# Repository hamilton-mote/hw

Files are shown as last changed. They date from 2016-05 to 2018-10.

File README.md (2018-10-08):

# Hamilton open-source hardware

hamilton mote

The Hamilton mote (so named for its $10 cost) is a mote based on the ATSAMR21E18A (similar to the MCU present on the Atmel SAMR21XPRO). The low-cost variboard has an accelerometer, a temperature sensor and a light sensor as well as four GPIO pins and an I2C bus. To disseminate sensor data, it uses the 802.15.4 wireless radio built into the SAMR21. The board is not designed to offer huge amounts of GPIO (the [storm](http://storm.rocks) is designed for that), but rather be a platform for low cost wireless sensors that can be deployed en-masse without massive financial outlay.

The primary operating system we support is RIOT-OS. Soon we hope to get support upstream into the RIOT codebase, but for now we will maintain a rebasing fork, broken into feature-branches that can be individually merged on top of upstream.

# Sensor packages

A hamilton board will have a sensor variant designator in its name, for example hamilton-3 or hamilton-1f. This variant indicates the presence of a subset of the following sensors

| Designation  | Description | Part number |
|:---:|:---:|:---:|
|  1 | Low-cost temperature sensor | AT30TS74 |
|  2 | Low-cost 3-axis accelerometer | MMA7660 |
|  4 | Light sensor | APDS-9007 |
|  8 | High-precision 3-axis accel/magnetometer | FXOS8700 |
| 10 | Temp / Humidity sensor | HDC1080 |
| 20 | Temp / Radiant sensor | TMP006 |
| 40 | PIR sensor | EKMB110x11x |
| 80 | Ultrasonic ranger | CH201 |
| 100 | High-precision 3-axis accel/magnetometer | LSM303C |
| 200 | Light sensor | ISL29035 |

So far, we have produced three hamilton bundles:

- Hamilton-7 (4+2+1), which costs $10 including the sensors and is designed for cost-sensitive applications
- Hamilton-3C (20+10+8+4), cost TBD, which is designed as an operative temperature sensor with acceleration/magnetometer so it can determine its orientation in the space
- Hamilton-7C (40+20+10+8+4), cost TBD, which adds occupancy (the occupancy sensor doubles the cost of the board)
- Hamilton-330 (200+100+20+10), a replacement for the 3C which has better light sensing and a more readily available accelerometer
- Hamilton-370 (200+100+40+20+10), a replacement for the 7C which adds PIR to the 330

The expected battery life of each of these variants will be put on here when they have been characterised

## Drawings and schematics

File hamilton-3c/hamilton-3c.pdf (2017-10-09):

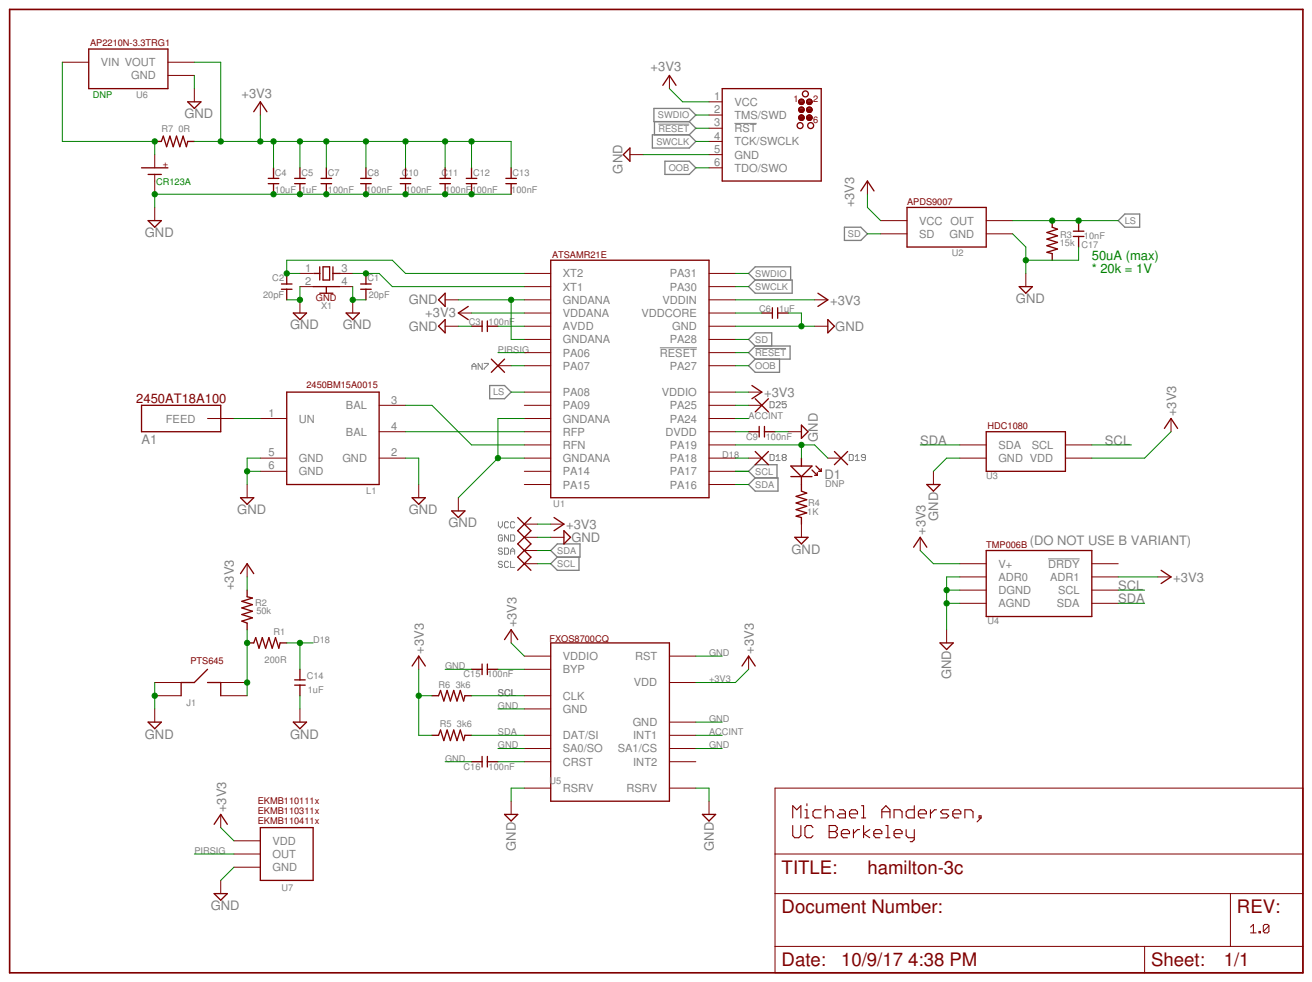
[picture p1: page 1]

XT2 XT1 GNDANA
PA06 PA07 PA08 PA09 GNDANA RFP RFN GNDANA

(DO NOT USE B VARIANT)
SCL ADR1 DRDY

Document Number: | REV:

Date: 10/9/17 4:38 PM | Sheet: 1/1

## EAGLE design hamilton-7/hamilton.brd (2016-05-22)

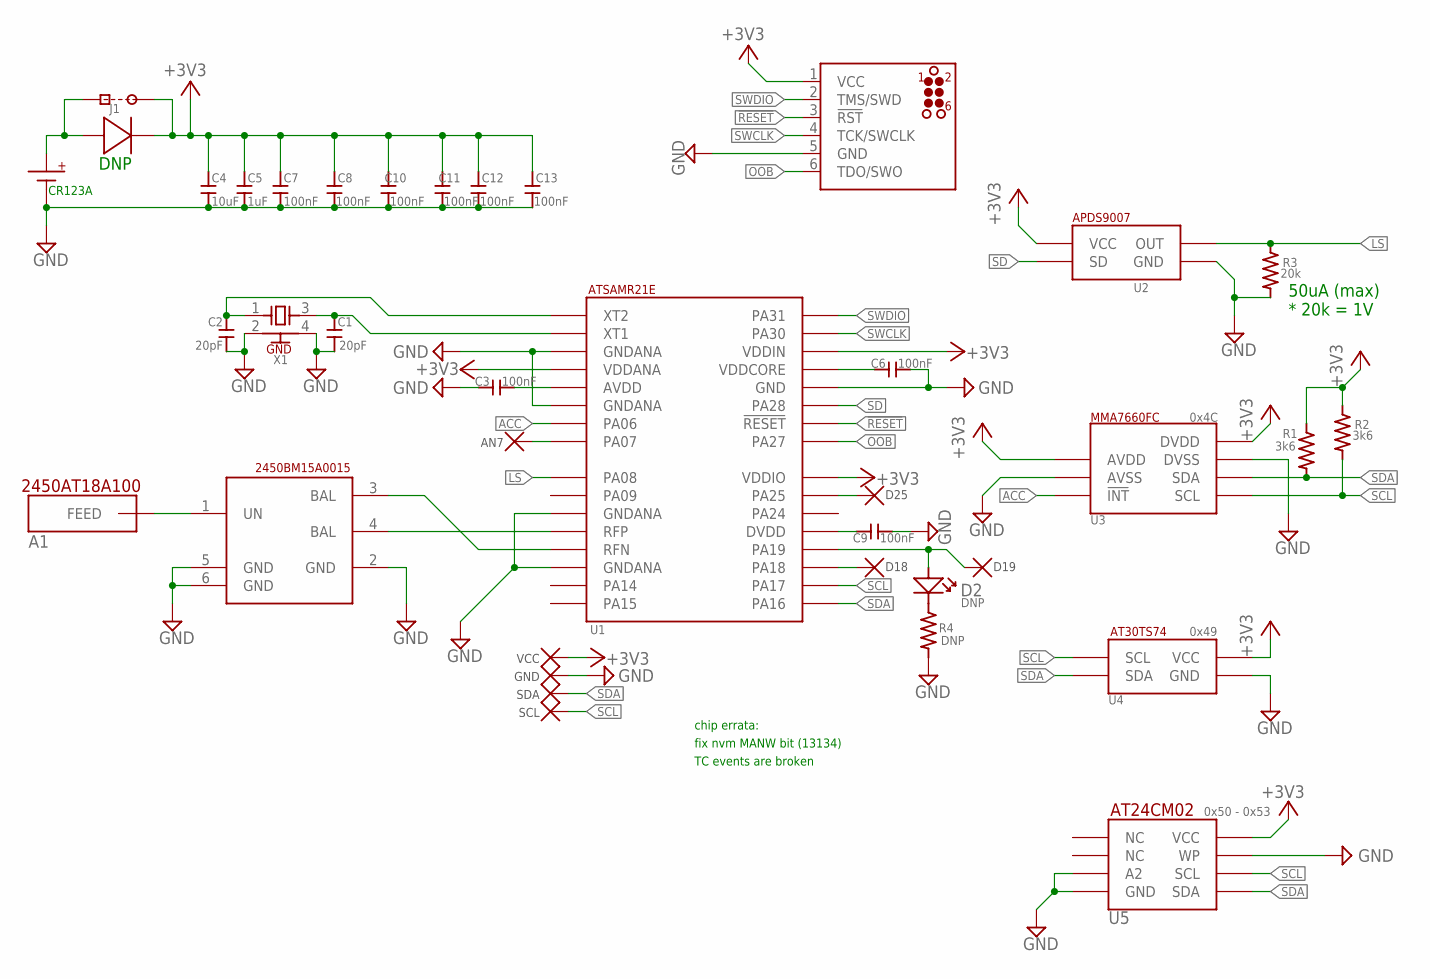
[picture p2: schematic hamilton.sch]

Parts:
A1: JOHANSON_ANTENNA2
BT1: 2/3A
C1, C2: 20pF; S0402
C3, C6, C7, C8, C9, C10, C11, C12, C13: 100nF; C0402
C4: 10uF; 0805
C5: 1uF; C0402
D1: SOD523F
D2: DNP; LINE_0805
J1: CUTJ2; CUT3
L1: BALUN_JOHANSON
R1, R2: 3k6; S0402
R3: 20k; S0402
R4: DNP; S0402
TP1: D19; TPP
TP2: D18; TPP
TP3: AN7; TPP
TP4: D25; TPP
TP5: VCC; TPP
TP6: GND; TPP
TP7: SDA; TPP
TP8: SCL; TPP
U1: SAMR21; QFN32
U2: APDS9007
U3: MMA7660FC; MMA7660
U4: AT30TS74; 4WLCSP
U5: AT24CM02; SO8
U$1: JLINK_CONNECT; TC2030-MCP-NL
X1: XTAL

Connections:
!RESET!: U1.26 (!RESET!), U$1.3 (!RST!)
+3V3: C4.2, C5.2, C7.1, C8.1, C10.1, C11.1, C12.1, C13.1, D1.NEG, J1.P$1 (R), R1.P$2, R2.P$2, TP5.P$1, U1.4 (VDDANA), U1.24 (VDDIO), U1.30 (VDDIN), U2.4 (VCC), U3.3 (AVDD), U3.9 (DVDD), U4.A1 (VCC), U5.8 (VCC), U$1.1 (VCC)
ACC: U1.7 (PA06), U3.5 (!INT!)
GND: BT1.NEG (-), C1.P$1, C2.P$1, C3.2, C4.1, C5.1, C6.1, C7.2, C8.2, C9.1, C10.2, C11.2, C12.2, C13.2, L1.2 (GND), L1.5 (GND), L1.6 (GND), R3.P$1, R4.P$1, TP6.P$1, U1.3 (GNDANA), U1.6 (GNDANA), U1.11 (GNDANA), U1.14 (GNDANA), U1.28 (GND), U2.1 (GND), U3.4 (AVSS), U3.8 (DVSS), U4.A2 (GND), U5.3 (A2), U5.4 (GND), U5.7 (WP), U$1.5 (GND), X1.2 (GND), X1.4 (GND)
LS: R3.P$2, U1.9 (PA08), U2.3 (OUT)
unnamed: BT1.POS (+), D1.POS, J1.P$2 (SQ)
unnamed: L1.3 (BAL), U1.13 (RFN)
unnamed: A1.FEED, L1.1 (UN)
unnamed: C2.P$2, U1.1 (XT2), X1.1 (X1)
unnamed: C6.2, U1.29 (VDDCORE)
unnamed: C3.1, U1.5 (AVDD)
unnamed: C1.P$2, U1.2 (XT1), X1.3 (X2)
unnamed: TP3.P$1, U1.8 (PA07)
unnamed: TP4.P$1, U1.23 (PA25)
unnamed: C9.2, U1.21 (DVDD)
unnamed: D2.NOLINE (+), TP1.P$1, U1.20 (PA19)
unnamed: TP2.P$1, U1.19 (PA18)
unnamed: L1.4 (BAL), U1.12 (RFP)
unnamed: D2.LINE (-), R4.P$2
OOB: U1.25 (PA27), U$1.6 (TDO/SWO)
SCL: R2.P$1, TP8.P$1, U1.18 (PA17), U3.6 (SCL), U4.B2 (SCL), U5.6 (SCL)
SD: U1.27 (PA28), U2.6 (SD)
SDA: R1.P$1, TP7.P$1, U1.17 (PA16), U3.7 (SDA), U4.B1 (SDA), U5.5 (SDA)
SWCLK: U1.31 (PA30), U$1.4 (TCK/SWCLK)
SWDIO: U1.32 (PA31), U$1.2 (TMS/SWD)

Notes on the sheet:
chip errata:
fix nvm MANW bit (13134)
TC events are broken
CR123A
DNP
50uA (max) * 20k = 1V
0x49
0x4C
0x50 - 0x53

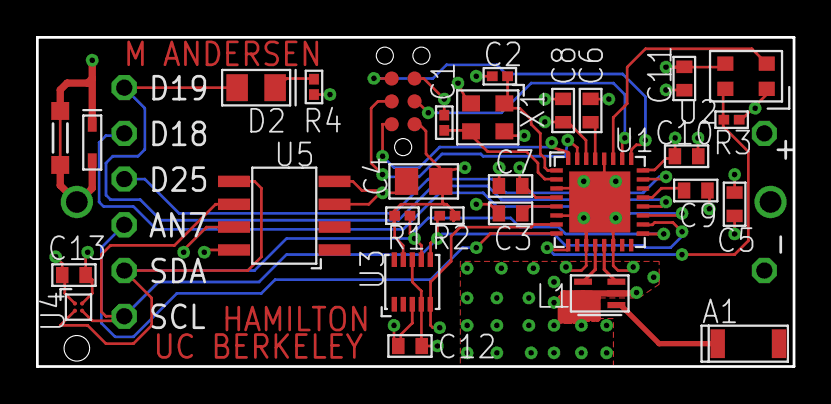
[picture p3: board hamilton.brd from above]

Board: 4 copper layers, 42.0 x 18.3 mm, 38 parts (1 on the bottom side), 25 nets.

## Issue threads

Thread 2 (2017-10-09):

Board files don't match produced boards

ppannuto, 2017-10-09:
I've identified:
 - rightmost sensor as the HDC1080 (a "10")
 - upper right as the APDA-9007 (a "4")
 - left of the SAMR21 as the FXOS8700 (an "8")
 - just below the SAMR21 as the balun
 - top left of the SAMR21 as the crystal
 - and hiding at the top left of the board a AT30TS74 (a "1")

I don't know what I have, but it doesn't match the table for a 3C, so I have a (1+4+8+10)?

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

@Hyungsin this is going to be a problem for everyone trying to figure out what they need to power off if they can't figure out what's on the board -- @nealjack @adkinsjd and I struggled for half an hour to figure out what's going on and I think this is right?

Hyungsin, 2017-10-09:
Hi Pat,

This is what you have.
I will announce it. Thanks.
Also, can you present two papers together on 10/19? Tock and Oppcast.

[image: Inline image 1]

-----------------------------------------------------------------------
*Hyung-Sin Kim*
Postdoctoral Researcher
Electrical Engineering and Computer Science
University of California, Berkeley
Homepage:
https://sites.google.com/site/netlabhome/people/alumni/hyung-sin-kim

On Sun, Oct 8, 2017 at 6:38 PM, Pat Pannuto <notifications@github.com>
wrote:

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

ppannuto, 2017-10-09:
Are the I/O connections correct?

What are the addresses of each sensor? The schematic in this repo doesn't even have the FXOS8700 in it at all.

immesys, 2017-10-09:
Sorry, the files in here are for the Hamilton-7 (the one that actually really costs less than $10). I will consolidate the files for the 3C and 7C into this repo on Monday as well.

immesys, 2017-10-09:
Also, you probably have a 3C. The chip you identified as a AT30TS74 is probably a TMP006

immesys, 2017-10-09:
I moved the 3C hardware into this repo.

Closed 2017-10-09.

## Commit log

2016-05-22 Add internal versions of hardware
    [hamilton.brd, hamilton.sch]
2017-09-28 fix light sensor part number
2017-10-09 Add the hamilton 3C hardware to the same repo
    [hamilton-3c.brd, hamilton-3c.sch, hamilton.brd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]

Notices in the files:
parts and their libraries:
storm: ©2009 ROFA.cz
